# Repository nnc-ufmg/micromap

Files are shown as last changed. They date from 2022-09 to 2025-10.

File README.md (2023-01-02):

MicroMAP: Low cost, high performance package for electrophysiological recording
===============================================================================
<div align="center">
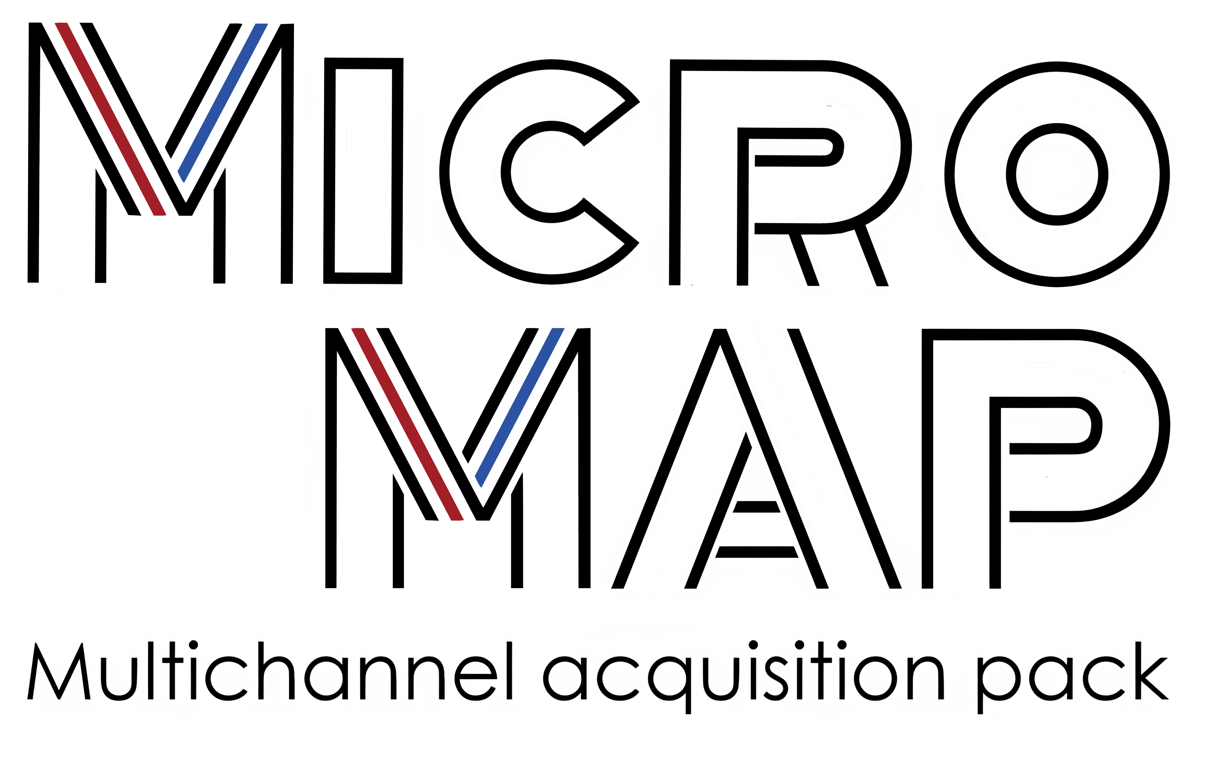
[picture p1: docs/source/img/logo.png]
MicroMAP software
    

<br/>
<br/>

 **About**

**MicroMAP** is a Python based electrophysiological aquisition system that combines the
portability of the raspberry pi and the versatility of the intan chip to harness the powerful 
combination of open source hardware and software to create a low cost, high performance package
for electrophysiological recording.

 **Getting started**

To get started, please see the installation page in the documentation. There you will find instructions on how to install MicroMAP on your raspberry pi and how to get started with the software.

 **Documentation**

_Online link coming soon_

<br/>

_**Note**_
 _This project is currently in its working beta phase._

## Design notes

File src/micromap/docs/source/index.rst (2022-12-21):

===============================================================================
MicroMAP: Low cost, high performance package for electrophysiological recording
===============================================================================

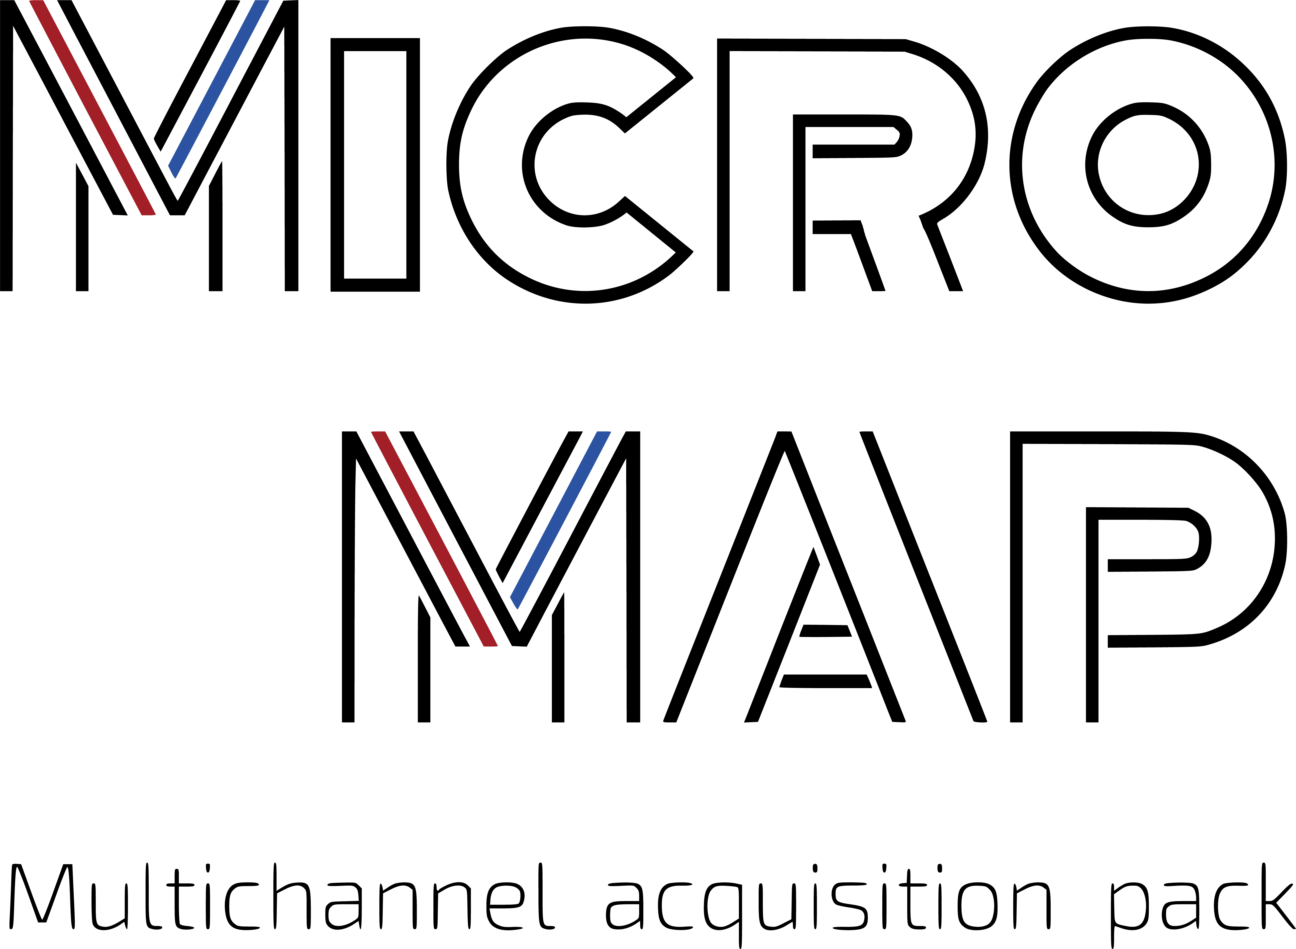
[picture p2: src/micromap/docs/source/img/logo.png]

   
|

.. toctree::
   :hidden:
   :maxdepth: 3

   installation
   modules
   mounting
   tips
   usage

**MicroMAP** is a Python based electrophysiological aquisition system that combines the
portability of the raspberry pi and the versatility of the intan chip to harness the powerful 
combination of open source hardware and software to create a low cost, high performance package
for electrophysiological recording.

To get started, please see the :doc:`/installation` page.
There you will find instructions on how to install MicroMAP on your raspberry pi and how to get started 
with the software.

**Get started**
---------------

* For tips about how to use the software, please see the :doc:`/tips` page
* For a list of all the available options and more detailed information, please see the :doc:`/micromap` page 
* Check out the :doc:`/usage` section for a detailed description of how to use the software

.. note::

  This project is currently in its working beta phase.

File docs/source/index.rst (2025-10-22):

MicroMAP
========

   
|

####################
Welcome to MicroMAP
####################

MicroMAP is a low-cost, multi-channel electrophysiology acquisition system. This documentation provides instructions for installing the necessary software, setting up the hardware, and building the components.

All codes, 3D models, and PCB designs are available at the project's GitHub repository: https://github.com/nnc-ufmg/micromap.

.. toctree::
   :maxdepth: 2
   :caption: Contents:

   installation_python
   installation_arduino
   building_micromap
   building_headstage
   modules/interface_functions
   modules/user_interface

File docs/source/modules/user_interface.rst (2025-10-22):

Interface Visual module
==========================

This module contains functions that are used to display the data acquired by the RHD2000 chip.

These functions are dealing with the interface as a whole. TIn other words, they contain the front-end in which the user will be able 
to choose the acquisition parameters such as sampling frequency, filters and number of channels active during the acquisition.

.. automodule:: micromap.interface.user_interface
   :members:
   :show-inheritance:

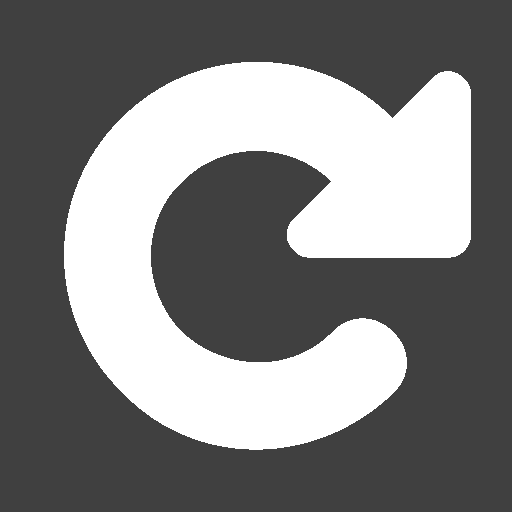
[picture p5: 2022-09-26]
src/micromap/interface/icon/nnc_update_button.png

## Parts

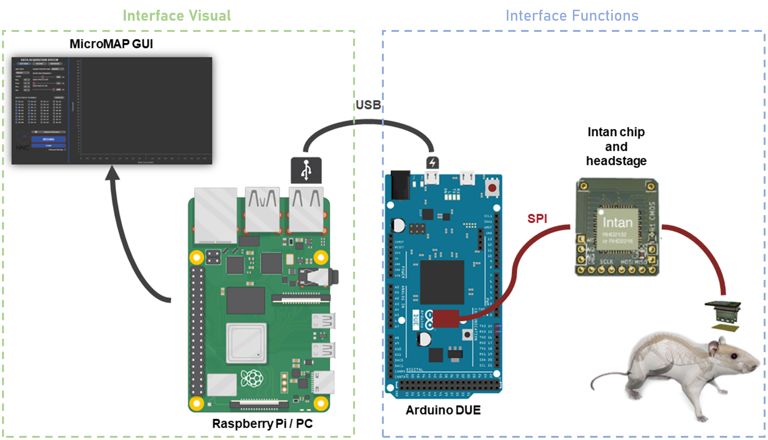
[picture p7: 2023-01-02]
docs/source/img/parts.png

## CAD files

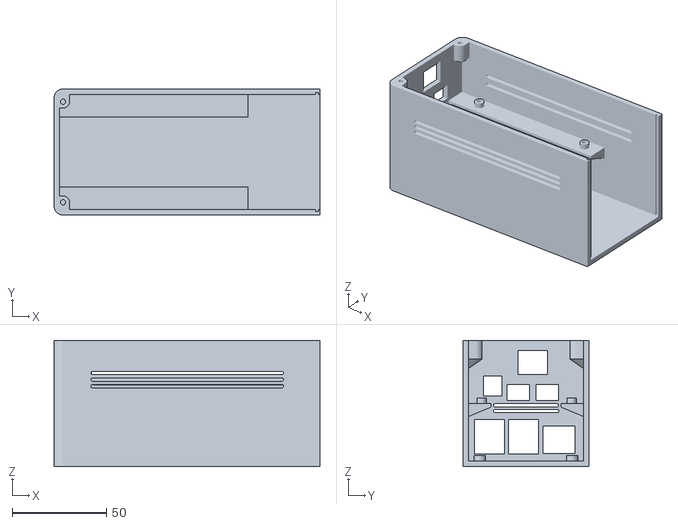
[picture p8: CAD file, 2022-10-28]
src/micromap/case_model/system_case_V2_base.stl
141.2 x 67.0 x 67.1

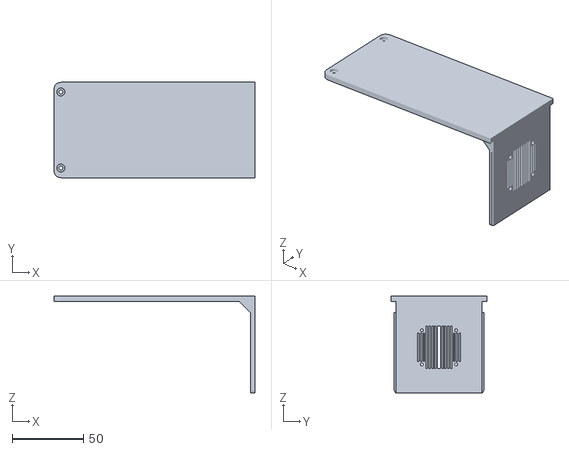
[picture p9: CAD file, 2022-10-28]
src/micromap/case_model/system_case_V2_cover.stl
141.0 x 67.0 x 67.9

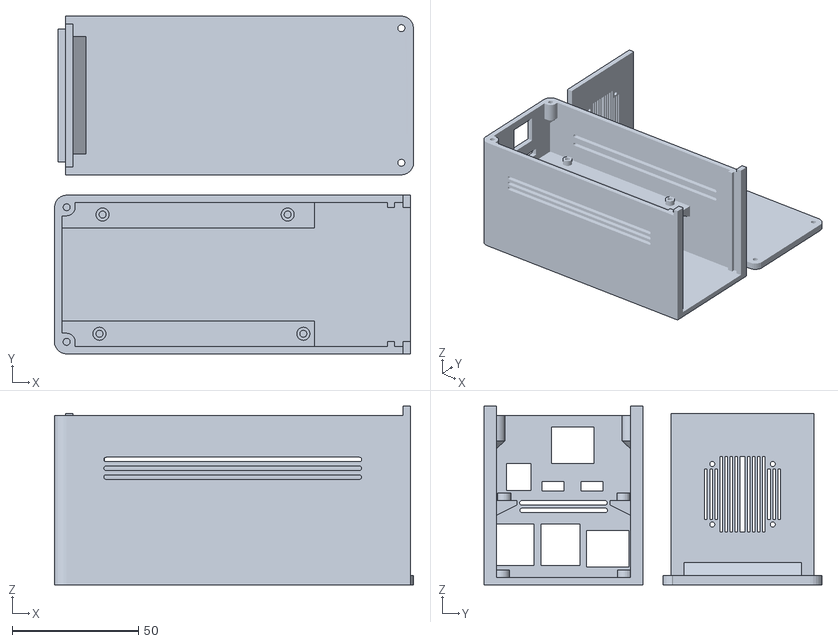
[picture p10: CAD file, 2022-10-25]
src/micromap/case_model/system_case_v2.stl
142.4 x 134.0 x 70.9

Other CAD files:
src/micromap/case_model/arduino_due.skp
src/micromap/case_model/raspberrypi_4.skp

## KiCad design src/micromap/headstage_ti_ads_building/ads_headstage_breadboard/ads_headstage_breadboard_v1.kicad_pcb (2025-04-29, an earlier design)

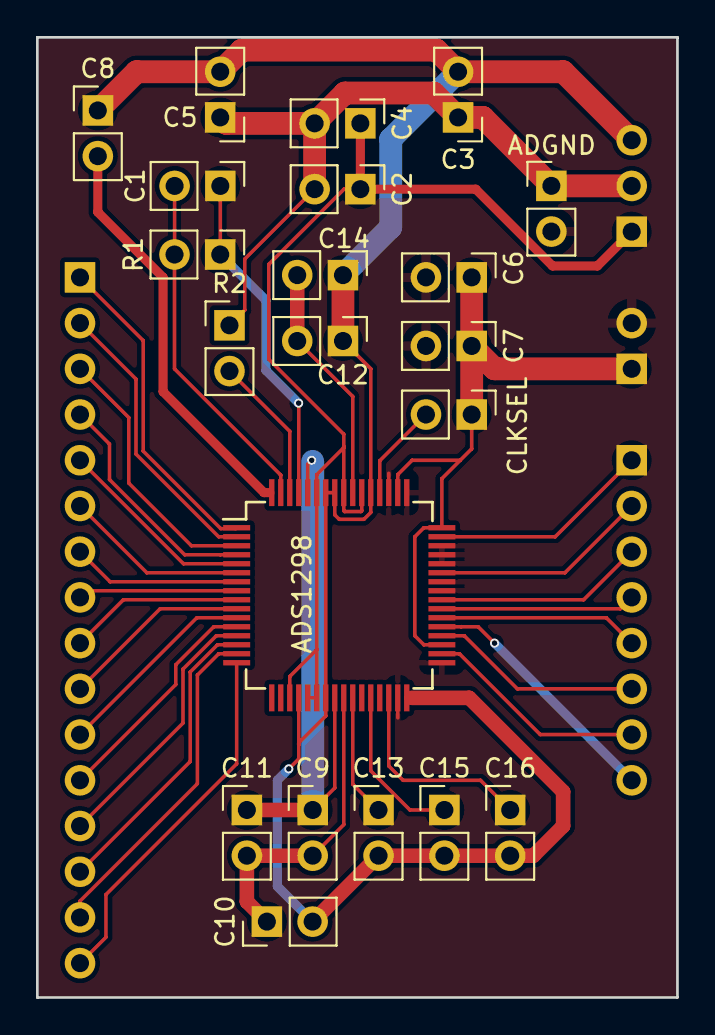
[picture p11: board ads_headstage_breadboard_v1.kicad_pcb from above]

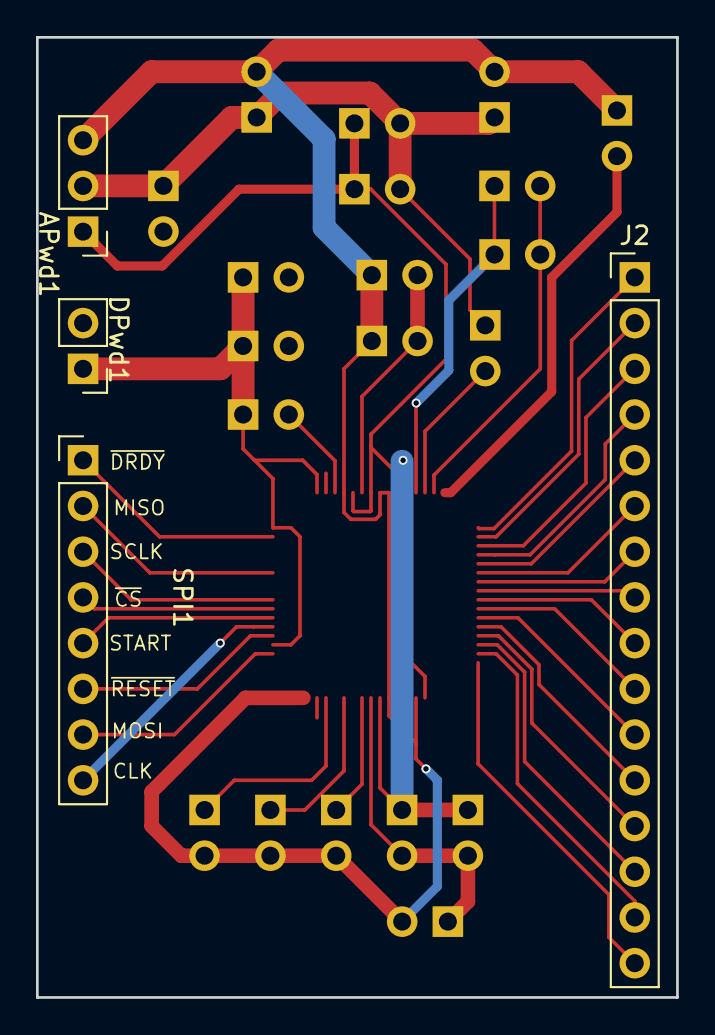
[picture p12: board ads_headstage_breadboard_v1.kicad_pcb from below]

Board: 2 copper layers, 35.6 x 53.3 mm, 25 parts (4 on the bottom side), 40 nets.

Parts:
ADGND: Jumper_NO_Small; PinHeader_1x02_P2.54mm_Vertical
ADS1298: ADS1298; TQFP-64_10x10mm_Pitch0.5mm
APwd1: Conn_01x03; PinHeader_1x03_P2.54mm_Vertical
C1: 1nf; PinHeader_1x02_P2.54mm_Vertical
C2, C3, C6, C10, C12, C13, C16: 1uF; PinHeader_1x02_P2.54mm_Vertical
C4, C5, C7, C9, C14: 0.1uF; PinHeader_1x02_P2.54mm_Vertical
C8: 100pf; PinHeader_1x02_P2.54mm_Vertical
C11: 10uF; PinHeader_1x02_P2.54mm_Vertical
C15: 22uF; PinHeader_1x02_P2.54mm_Vertical
CLKSEL: Jumper_NO_Small; PinHeader_1x02_P2.54mm_Vertical
DPwd1: Conn_01x02; PinHeader_1x02_P2.54mm_Vertical
J2: Conn_01x16_Female; PinHeader_1x16_P2.54mm_Vertical
R1, R2: 1M; PinHeader_1x02_P2.54mm_Vertical
SPI1: Conn_01x08; PinHeader_1x08_P2.54mm_Vertical

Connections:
/ADS1298/RLDIN: ADS1298.62, R2.2
/ADS1298/RLDINV: ADS1298.61, C1.1, R1.1
/ADS1298/RLDREF: ADS1298.24, ADS1298.60, C9.1, C11.1
/AGND: ADGND.1, APwd1.2, C2.2, C3.1, C4.2, C5.1, R2.1
/AVDD: ADS1298.19, ADS1298.21, ADS1298.22, ADS1298.54, ADS1298.56, ADS1298.59, APwd1.1, C2.1, C4.1
/AVSS: ADS1298.20, ADS1298.23, ADS1298.32, ADS1298.53, ADS1298.57, ADS1298.58, APwd1.3, C3.2, C5.2, C8.1, C10.2, C12.1, C13.2, C14.1, C15.2, C16.2
/CLK: ADS1298.37, SPI1.8
/CLKSEL: ADS1298.52, CLKSEL.2
/DGND: ADGND.2, ADS1298.31, ADS1298.33, ADS1298.41, ADS1298.42, ADS1298.44, ADS1298.45, ADS1298.46, ADS1298.49, ADS1298.51, C6.2, C7.2, DPwd1.2
/DVDD: ADS1298.35, ADS1298.48, ADS1298.50, C6.1, C7.1, CLKSEL.1, DPwd1.1
/IN1N: ADS1298.15, J2.15
/IN1P: ADS1298.16, J2.16
/IN2N: ADS1298.13, J2.13
/IN2P: ADS1298.14, J2.14
/IN3N: ADS1298.11, J2.11
/IN3P: ADS1298.12, J2.12
/IN4N: ADS1298.9, J2.9
/IN4P: ADS1298.10, J2.10
/IN5N: ADS1298.7, J2.7
/IN5P: ADS1298.8, J2.8
/IN6N: ADS1298.5, J2.5
/IN6P: ADS1298.6, J2.6
/IN7N: ADS1298.3, J2.3
/IN7P: ADS1298.4, J2.4
/IN8N: ADS1298.1, J2.1
/IN8P: ADS1298.2, J2.2
/MISO: ADS1298.43, SPI1.2
/MOSI: ADS1298.34, SPI1.7
/RDLout: ADS1298.63, C1.2, R1.2
/SPI_CLK: ADS1298.40, SPI1.3
/START: ADS1298.38, SPI1.5
/~CS: ADS1298.39, SPI1.4
/~DRDY: ADS1298.47, SPI1.1
/~RESET: ADS1298.36, SPI1.6
unnamed: ADS1298.25, C9.2, C10.1, C11.2
unnamed: ADS1298.26, C13.1
unnamed: ADS1298.28, C15.1
unnamed: ADS1298.30, C16.1
unnamed: ADS1298.55, C12.2, C14.2
unnamed: ADS1298.64, C8.2

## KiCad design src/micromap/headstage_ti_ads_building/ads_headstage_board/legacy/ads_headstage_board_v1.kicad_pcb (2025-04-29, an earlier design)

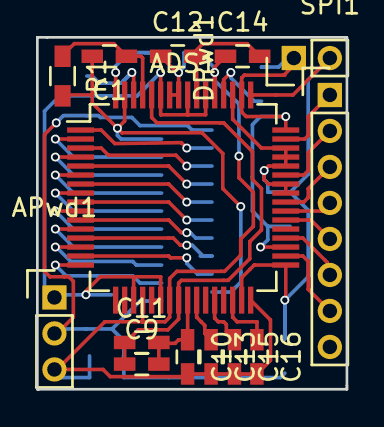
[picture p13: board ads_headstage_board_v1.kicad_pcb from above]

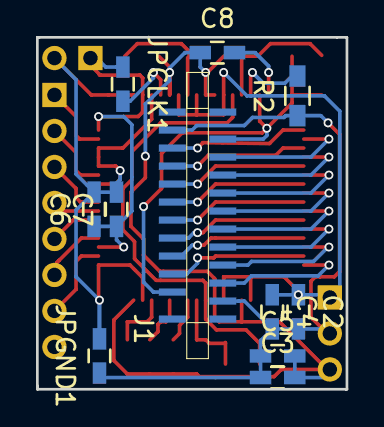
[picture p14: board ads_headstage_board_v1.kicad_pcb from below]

Board: 2 copper layers, 17.2 x 19.5 mm, 25 parts (11 on the bottom side), 39 nets.

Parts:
ADS1: ADS1298; TQFP-64_10x10mm_Pitch0.5mm
APwd1: Conn_01x03; Pin_Header_Straight_1x03_Pitch2.00mm
C1: 1nf; C_0603_HandSoldering
C2, C3, C6, C10, C12, C13, C16: 1uF; C_0603_HandSoldering
C4, C5, C7, C9, C14: 0.1uF; C_0603_HandSoldering
C8: 100pf; C_0603_HandSoldering
C11: 10uF; C_0603_HandSoldering
C15: 22uF; C_0603_HandSoldering
DPwd1: Conn_01x02; Pin_Header_Straight_1x02_Pitch2.00mm
J1: FFCfemale20
JPCLK1: Jumper_NO_Small; C_0603_HandSoldering
JPGND1: Jumper_NO_Small; C_0603_HandSoldering
R1, R2: 1M; R_0603_HandSoldering
SPI1: Conn_01x08; Pin_Header_Straight_1x08_Pitch2.00mm

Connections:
/ADS1298/RLDIN: ADS1.62, R2.2
/ADS1298/RLDINV: ADS1.61, C1.1, R1.1
/ADS1298/RLDREF: ADS1.24, ADS1.60, C9.1, C11.1
/AGND: APwd1.2, C2.2, C3.1, C4.2, C5.1, J1.1, J1.20, JPGND1.1, R2.1
/AVDD: ADS1.19, ADS1.21, ADS1.22, ADS1.54, ADS1.56, ADS1.59, APwd1.1, C2.1, C4.1
/AVSS: ADS1.20, ADS1.23, ADS1.32, ADS1.53, ADS1.57, ADS1.58, APwd1.3, C3.2, C5.2, C8.1, C10.2, C12.1, C13.2, C14.1, C15.2, C16.2
/CLKSEL: ADS1.52, JPCLK1.2
/DGND: ADS1.31, ADS1.33, ADS1.41, ADS1.42, ADS1.44, ADS1.45, ADS1.46, ADS1.49, ADS1.51, C6.2, C7.2, DPwd1.2, JPGND1.2
/DVDD: ADS1.35, ADS1.48, ADS1.50, C6.1, C7.1, DPwd1.1, JPCLK1.1
/IN1N: ADS1.15, J1.17
/IN1P: ADS1.16, J1.18
/IN2N: ADS1.13, J1.15
/IN2P: ADS1.14, J1.16
/IN3N: ADS1.11, J1.13
/IN3P: ADS1.12, J1.14
/IN4N: ADS1.9, J1.11
/IN4P: ADS1.10, J1.12
/IN5N: ADS1.7, J1.9
/IN5P: ADS1.8, J1.10
/IN6N: ADS1.5, J1.7
/IN6P: ADS1.6, J1.8
/IN7N: ADS1.3, J1.5
/IN7P: ADS1.4, J1.6
/IN8N: ADS1.1, J1.3
/IN8P: ADS1.2, J1.4
/MISO: ADS1.43, SPI1.2
/MOSI: ADS1.34, SPI1.7
/RDLout: ADS1.63, C1.2, J1.2, J1.19, R1.2
/SPI_CLK: ADS1.40, SPI1.3
/START: ADS1.38, SPI1.5
/~CS: ADS1.39, SPI1.4
/~DRDY: ADS1.47, SPI1.1
/~RESET: ADS1.36, SPI1.6
unnamed: ADS1.25, C9.2, C10.1, C11.2
unnamed: ADS1.26, C13.1
unnamed: ADS1.28, C15.1
unnamed: ADS1.30, C16.1
unnamed: ADS1.55, C12.2, C14.2
unnamed: ADS1.64, C8.2

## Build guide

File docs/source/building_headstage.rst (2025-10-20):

###########################
4. Building the Headstage
###########################

MicroMAP uses a custom horizontal headstage designed to be low-cost and reduce torque on the animal's head. The system is compatible with two main headstage designs:

* **Texas Instruments (TI) ADS1298**
* **Intan RHD2000 family**

1. Fabrication
==============

* **Get PCB Designs**: The printed circuit board (PCB) designs, created in **KICAD 8**, are available on the project's GitHub.
* **Fabricate PCBs**: Fabricate the main headstage PCB based on the KiCAD files.
* **Fabricate Connector Plug**: A flat connector plug, implemented as a double-sided PCB, is also required. This design uses plated through-holes for soldering the electrodes.

2. Assembly
===========

* **Attach ADC**: The ADC (e.g., ADS1298 or RHD) is attached to the **top layer** of the headstage PCB.
* **Attach Socket**: A 20-pin connector socket is attached to the **bottom layer** of the PCB. This socket interfaces with the flat connector plug.

Refer to Figure 2A (ADS) and 2B (RHD) for 3D renderings and circuit schematics of the headstages.

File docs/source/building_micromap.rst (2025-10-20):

###########################
3. Building the MicroMAP
###########################

This section describes the assembly of the MicroMAP enclosure, which houses the core components.

1. 3D Printing the Enclosure
============================

The system is housed in a custom enclosure ($140~mm \times 65~mm \times 67~mm$).

* **Get 3D Models**: All 3D models are available on the project's GitHub.
* **Print**: Fabricate the enclosure from PLA plastic using a 3D printer.

2. Component Assembly
=====================
The enclosure is designed to house the **Arduino Due** and a **Raspberry Pi** (RPi).

* Install the Arduino Due and RPi into their designated slots in the 3D-printed case.
* (Optional) A fan can be added for cooling, powered by the RPi's 5V and ground pins.

3. Wiring
=========

The system requires wiring between the Arduino and an external connector (e.g., RJ45) to interface with the headstage.

* **RHD Headstage**: Requires an 8-contact RJ45 connector, using 6 terminals.
* **ADS Headstage**: Requires a 12-contact connector or similar interface.

Refer to Figure 1A and Supplementary Table 2 in the manuscript for detailed wiring schemes between the Arduino and the headstage connector.

Finally, connect the Arduino ground to a pin fixed to the enclosure to ensure proper grounding.

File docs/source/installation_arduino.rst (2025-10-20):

###################################
2. Installing the Arduino Interface
###################################

The MicroMAP system uses an **Arduino Due** as the microcontroller to handle communication and control of the ADC chipsets (Intan RHD or TI ADS).

Hardware & Software Requirements
================================

* **Hardware**: Arduino Due
* **Software**: Arduino IDE

Uploading the Code
==================

The microcontroller code is programmed in C++ and must be uploaded to the Arduino Due.

1.  **Download the Code**

    The microcontroller code is available in the same GitHub repository.

2.  **Open in Arduino IDE**

    Launch the Arduino IDE and open the `.ino` file for the microcontroller found in the downloaded repository.

3.  **Configure the IDE**

    * Connect your Arduino Due to the computer via USB.
    * In the Arduino IDE, go to ``Tools > Board`` and select "Arduino Due (Programming Port)".
    * Go to ``Tools > Port`` and select the COM or tty port corresponding to your Arduino Due.

4.  **Upload**

    Click the "Upload" button (right-arrow icon) in the Arduino IDE to compile and upload the code to the Arduino Due.

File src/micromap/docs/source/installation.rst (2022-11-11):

Installation
============

To get the program up and running of your Raspberry Pi
you will need to:

1. Install Raspberry Pi OS 
2. Configure the VNC package in the Raspberry Pi
3. Install the the dependecies on the Raspberry Pi

Raspberry Pi OS installation
------------------------------

- Install the Raspberry Pi OS on your Raspberry Pi

Raspberry Pi VNC Configuration
------------------------------

- Open the *Raspbperry Pi Configurations* in *Applications Menu*
- Go to *Interfaces* tab and turns on the VNC
- Go to *Display* tab and sets the *Headlesss Resolution* to maximum value (1920x1080)
- On the task bar right side a VNC symbol will appear
- Click on it and gets the IP on left side of the window (ex. 192.168.1.222)
- Install and open the *VNC Viewer* on another computer (https://www.realvnc.com/pt/connect/download/viewer/)
- Open the *VNC Viewer*, click in *file* tab and after, in *new connection* 
- Put the Raspberry Pi VNC IP on *VNC Server* item and complete with the login
- Turns on the Raspberry Pi and connect with VNC Viewer to acess remotely

Installing dependecies
----------------------

- Open a terminal inside the Raspberry Pi
- Install the libraries with the command:

.. code-block:: bash

  $ pip install -r requirements.txt

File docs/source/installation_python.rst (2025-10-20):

#################################
1. Installing Python and MicroMAP
#################################

The MicroMAP system uses a cross-platform Graphical User Interface (GUI) developed in Python 3.12 with the PyQt5 library. This GUI runs on a host computer or a microcomputer like a Raspberry Pi.

Prerequisites
=============

* Python 3.12 or newer
* Git (for cloning the repository)

Installation Steps
==================

1.  **Download the Software**

    First, download the software from the official GitHub repository.

    .. code-block:: bash

        $ git clone https://github.com/nnc-ufmg/micromap.git
        $ cd micromap

2.  **Install Dependencies**

    The GUI requires specific Python dependencies to run. Install them using the provided requirements file (assumed to be on GitHub). The primary dependency is PyQt5.

    .. code-block:: bash

        $ pip install -r requirements.txt 

3.  **Run the GUI**

    Once dependencies are installed, you can run the program from an IDE or directly via the command line.

    .. code-block:: bash

        $ python interface_visual.py

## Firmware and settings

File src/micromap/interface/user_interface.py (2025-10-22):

# ELECTROPHYSIOLOGICAL DATA ACQUISITION SYSTEM

# This code is the configuration part of the electrophysiology recording 
# system. This partition contains the front-end, in which the user will be able 
# to choose acquisition parameters such as sampling frequency, filters and number 
# of channels.

# Author: 
#     João Pedro Carvalho Moreira
#     Belo Horizonte, Minas Gerais, Brasil
#     Graduated in Eletrical Engineer, UFSJ
#     PhD Student in Eletrical Engineer, UFMG
#     Member of Núcleo de Neurociências, UFMG

# Advisor: 
#     Márcio Flávio Dutra Moraes

#%% IMPORTS

import sys
import numpy 
import serial
import math
import serial.tools.list_ports
import time
import struct
import queue
from . import interface_functions as interface_functions      
import os
import platform
import pickle
from datetime import datetime, timedelta
from PyQt5 import QtWidgets, uic    
from PyQt5.QtCore import QThread, pyqtSignal, QCoreApplication, QTimer
from PyQt5.QtWidgets import QMessageBox, QMainWindow, QInputDialog, QFileDialog
import platform
from pyqtgraph.Qt import QtGui
import pyqtgraph

class DataReceiverThreadRHD(QThread):
    raw_data_ready = pyqtSignal(bytearray)
    message = pyqtSignal(str)

    def __init__(self, usb_port, num_channels, samples_to_read, is_recording_mode, plot_online, save_queue = None):
        super().__init__()
        self.usb = interface_functions.usb_singleton(usb_port, 50000000)
        self.num_channels = num_channels
        self.samples_to_read = samples_to_read
        self.bytes_to_read = int(samples_to_read*(2*(self.num_channels + 1)))                                                                         # Number of bytes to be read at a time (in this case, at a time will be read 1 sample = 2 bytes per channel + 1 byte header)
        self.running = False
        self.is_recording_mode = is_recording_mode
        self.save_queue = save_queue
        self.expected_counter = None
        self.buffer = bytearray()
        self.read_number = 0
        self.plot_online = plot_online
        self.packets_lost = []

    def run(self):
        self.running = True
        self.usb.connect()
        self.usb.clear_buffer()
        self.usb.request_acquisition()

        while self.running:
            if self.usb.port.in_waiting > 0:
                try:
                    partial_data = self.usb.port.read(self.usb.port.in_waiting)
                    self.buffer += partial_data

                    if self.plot_online:
                        self.raw_data_ready.emit(bytearray(partial_data))

                    while len(self.buffer) >= self.bytes_to_read:                      
                        full_packet = self.buffer[:self.bytes_to_read]
                        self.buffer = self.buffer[self.bytes_to_read:]

                        if self.expected_counter is None:
                            self.expected_counter = int.from_bytes( full_packet[0:2], byteorder='big')  # Convert to integer

                        packet_counter = int.from_bytes(full_packet[0:2], byteorder='big')  # Convert to integer
                        
                        if packet_counter != self.expected_counter:
                            self.message.emit(f"[ERROR] Packet counter mismatch: expected {self.expected_counter}, got {packet_counter}")
                            self.packets_lost.append(numpy.abs(packet_counter - self.expected_counter))  # Store the difference in packet counters
                            self.expected_counter = packet_counter                                       # Update the expected counter to the received one

                        self.expected_counter = (self.expected_counter + self.samples_to_read) % 65536  # Increment the expected counter

                        if self.is_recording_mode and self.save_queue:
                            self.save_queue.put(full_packet)  

                        self.message.emit(f'[RECEIVE] {self.read_number}')
                        self.read_number += 1

                except Exception as e:
                    self.message.emit(f"[ERROR]: {e}")

        if len(self.buffer) > 0:
            if self.is_recording_mode and self.save_queue:
                self.save_queue.put(self.buffer)
                self.message.emit(f'[RECEIVE] {self.read_number}')
                self.read_number += 1

        if self.packets_lost != []:
            self.message.emit(f"[INFO] Stopping data acquisition... ({numpy.sum(self.packets_lost)} packets lost)")
        else:
            self.message.emit(f"[INFO] Stopping data acquisition... (No packets lost)")
        self.usb.stop_acquisition()
        self.usb.disconnect()

    def stop(self):
        self.running = False

    def online_plotting(self, state):
        self.plot_online = state

class DataReceiverThreadADS(QThread):
    raw_data_ready = pyqtSignal(bytearray)
    message = pyqtSignal(str)

    def __init__(self, usb_port, num_channels, samples_to_read, is_recording_mode, plot_online, save_queue = None):
        super().__init__()
        self.usb = interface_functions.usb_singleton(usb_port, 50000000)
        self.num_channels = num_channels
        self.samples_to_read = samples_to_read
        self.bytes_to_read = int(samples_to_read*(216//8))                                                                                            # Number of bytes to be read at a time (in this case, at a time will be read 1 sample = 2 bytes per channel + 1 byte header)
        self.running = False
        self.is_recording_mode = is_recording_mode
        self.save_queue = save_queue
        self.expected_counter = None
        self.buffer = bytearray()
        self.read_number = 0
        self.plot_online = plot_online
        self.packets_lost = []

    def run(self):
        self.running = True
        self.usb.connect()
        self.usb.clear_buffer()
        self.usb.request_acquisition()

        while self.running:
            if self.usb.port.in_waiting > 0:
                try:
                    partial_data = self.usb.port.read(self.usb.port.in_waiting)
                    self.buffer += partial_data

                    if self.plot_online:
                        self.raw_data_ready.emit(bytearray(partial_data))

                    while len(self.buffer) >= self.bytes_to_read:                      
                        full_packet = self.buffer[:self.bytes_to_read]
                        self.buffer = self.buffer[self.bytes_to_read:]

                        if self.is_recording_mode and self.save_queue:
                            self.save_queue.put(full_packet)  

                        self.message.emit(f'[RECEIVE] {self.read_number}')
                        self.read_number += 1

                except Exception as e:
                    self.message.emit(f"[ERROR]: {e}")

        if len(self.buffer) > 0:
            if self.is_recording_mode and self.save_queue:
                self.save_queue.put(self.buffer)
                self.message.emit(f'[RECEIVE] {self.read_number}')
                self.read_number += 1

        if self.packets_lost != []:
            self.message.emit(f"[INFO] Stopping data acquisition... ({numpy.sum(self.packets_lost)} packets lost)")
        else:
            self.message.emit(f"[INFO] Stopping data acquisition... (No packets lost)")
        self.usb.stop_acquisition()
        self.usb.disconnect()

    def stop(self):
        self.running = False

    def online_plotting(self, state):
        self.plot_online = state

class PlotThreadRHD(QThread):
    channel_data_ready = pyqtSignal(numpy.ndarray)
    message = pyqtSignal(str)

    def __init__(self, num_channels, plot_data_window, update_samples = 1000, parent=None):
        super().__init__(parent)    
        if plot_data_window < update_samples:
            raise ValueError("plot_data_window must be greater than update_samples")
        
        self.queue = queue.Queue()
        self.num_channels = num_channels
        self.update_bytes = update_samples*(2*(self.num_channels + 1))
        self.intan_scale = 1000 * 0.195e-6
        self.running = True
        self.update_buffer = numpy.zeros((self.num_channels, plot_data_window), dtype = numpy.float32)
        self.update_index = 0
        self.buffer_size = self.update_buffer.shape[1]

        print(f"[INFO] Buffer size: {self.buffer_size}")

        self.block_size = 2*(self.num_channels + 1)  # 2 bytes por amostra + 2 bytes cabeçalho
        self.flag_indexes_template = numpy.ones(self.block_size, dtype = bool)
        self.flag_indexes_template[0:2] = False

    def push_data(self, byte_data):
        self.queue.put(byte_data)

    def run(self):
        accumulated_bytes = 0
        byte_block = bytearray()

        while self.running:
            try:
                byte_data = self.queue.get(timeout=0.1)
                byte_block.extend(byte_data)
                accumulated_bytes += len(byte_data)

                if accumulated_bytes >= self.update_bytes:
                    repeats = len(byte_block) // self.block_size
                    flag_indexes = numpy.tile(self.flag_indexes_template, repeats)
                    
                    # Processa o pacote
                    clean_bytes = numpy.frombuffer(byte_block, dtype = numpy.uint8)[flag_indexes].tobytes()
                    unpack_format = "<" + str(len(clean_bytes)//2) + "h"
                    values = struct.unpack(unpack_format, clean_bytes)
                    channel_data = numpy.array([values[i::self.num_channels] for i in range(self.num_channels)], dtype=numpy.float32)
                    channel_data = channel_data * self.intan_scale

                    # Atualiza buffer
                    update_length = channel_data.shape[1]
                    end_index = (self.update_index + update_length) % self.buffer_size

                    if self.update_index < end_index:
                        self.update_buffer[:, self.update_index:end_index] = channel_data
                    else:
                        first_part = self.buffer_size - self.update_index
                        self.update_buffer[:, self.update_index:] = channel_data[:, :first_part]
                        self.update_buffer[:, :update_length - first_part] = channel_data[:, first_part:]

                    self.update_index = end_index

                    self.channel_data_ready.emit(self.update_buffer.copy())

                    # Reseta acumuladores
                    accumulated_bytes = 0
                    byte_block = bytearray()

            except queue.Empty:
                continue
    
    def stop(self):
        self.running = False

class PlotThreadADS(QThread):
    channel_data_ready = pyqtSignal(numpy.ndarray)
    message = pyqtSignal(str)

    def __init__(self, num_channels, plot_data_window, update_samples=1000, parent=None):
        super().__init__(parent)
        if plot_data_window < update_samples:
            raise ValueError("plot_data_window must be greater than update_samples")

        self.queue = queue.Queue()
        self.num_channels = num_channels
        self.update_bytes = update_samples * (3 * (self.num_channels + 1))  # 3 bytes por canal + 3 de header
        self.ads_scale = 0.488e-6 * 1000  # microvolts para milivolts
        self.running = True
        self.update_buffer = numpy.zeros((self.num_channels, plot_data_window), dtype=numpy.float32)
        self.update_index = 0
        self.buffer_size = self.update_buffer.shape[1]

        print(f"[INFO] Buffer size: {self.buffer_size}")

        self.block_size = 3 * (self.num_channels + 1)  # 3 bytes de header + 3 bytes por canal
        self.flag_indexes_template = numpy.ones(self.block_size, dtype=bool)
        self.flag_indexes_template[0:3] = False  # Ignora os 3 bytes do status word

    def push_data(self, byte_data):
        self.queue.put(byte_data)

    def run(self):
        accumulated_bytes = 0
        byte_block = bytearray()

        while self.running:
            try:
                byte_data = self.queue.get(timeout=0.1)
                byte_block.extend(byte_data)
                accumulated_bytes += len(byte_data)

                if accumulated_bytes >= self.update_bytes:
                    repeats = len(byte_block) // self.block_size
                    flag_indexes = numpy.tile(self.flag_indexes_template, repeats)

                    # Remove status word
                    clean_bytes = numpy.frombuffer(byte_block, dtype=numpy.uint8)[flag_indexes].tobytes()

                    # Reconstrói os valores de 24 bits -> 32 bits assinados
                    values = []
                    for i in range(0, len(clean_bytes), 3):
                        b1, b2, b3 = clean_bytes[i:i+3]
                        val = b1 << 16 | b2 << 8 | b3
                        if val & 0x800000:
                            val -= 0x1000000  # Sign extension para 2's complement
                        values.append(val)

                    values = numpy.array(values, dtype=numpy.float32)
                    values *= self.ads_scale * 0.01

                    channel_data = numpy.array([values[i::self.num_channels] for i in range(self.num_channels)])

                    update_length = channel_data.shape[1]
                    end_index = (self.update_index + update_length) % self.buffer_size

                    if self.update_index < end_index:
                        self.update_buffer[:, self.update_index:end_index] = channel_data
                    else:
                        first_part = self.buffer_size - self.update_index
                        self.update_buffer[:, self.update_index:] = channel_data[:, :first_part]
                        self.update_buffer[:, :update_length - first_part] = channel_data[:, first_part:]

                    self.update_index = end_index
                    self.channel_data_ready.emit(self.update_buffer.copy())

                    # Reseta
                    accumulated_bytes = 0
                    byte_block = bytearray()

            except queue.Empty:
                continue

    def stop(self):
        self.running = False

class SaveThread(QThread):
    message = pyqtSignal(str)
    
    def __init__(self, filename, save_queue):
        super().__init__()
        self.save_queue = save_queue
        self.filename = filename
        self.running = True
        self.save_number = 0

    def run(self):
        with open(self.filename, 'wb') as f:
            while self.running or not self.save_queue.empty():
                try:
                    data = self.save_queue.get(timeout=0.1)
                    f.write(data)
                    f.flush()
                    self.message.emit(f'[SAVE] {self.save_number}')
                    self.save_number += 1
                except queue.Empty:
                    continue

    def stop(self):
        self.running = False

# INTERFACE CLASS
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

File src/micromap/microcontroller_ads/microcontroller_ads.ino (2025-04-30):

/*  INCLUDES
 *  Initializes the librarys that will be used
 */
#include "microcontroller_ads.h"

/*  SETUP THE COMMUNICATION
 *  This function initializes the USB and the SPI ports
 */
void setup() 
{
  SerialUSB.begin(50000000);                                                                      // Starts the high speed USB transfer port (50MB)
  USART0config(8); 
  ads_1298_chip.init_default(4, 13, 25, 53, 2000, 47);
}

/*  COMMUNICATION LOOP
 *  This function initializes the USB and the SPI communication
 */
void loop() 
{
  if(Serial.available())                                                                          // Deal with what comes via USB
  {
      
  }
  
  if(SerialUSB.available())                                                                       // Deal with what comes in via high speed USB
  {
    ads_1298_chip.setting_command();
  }
  
  if(transfer_data_flag)                                                                          // If has data in buffer (flag is True)
  {
    transfer_data_flag = false;                                                                   // Sets the flag to Flase
    SerialUSB.write((byte *)ads_1298_chip.buffer, 3*ads_1298_chip.channel_count + 3);
  }
}

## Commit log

2022-09-26 Version 0.0 files
    All the files that have been produced so far have been attached to the repository. This is the functional version 0.0 that we will start working on as a team
    [arduino_due.skp, raspberrypi_4.skp]
2022-09-26 Version 0.0 - Upload all files
    In this commit all files produced to build the system was uploaded. This is the version 0.0 and is the group work starting point.
    [arduino_due.skp, raspberrypi_4.skp]
2022-10-12 Fixed two buttons on the advanced tab Both CONTINUE TO RECORD and CANCEL were clipping through the command window.
    - Changed the size of the buttons
    - Moved the command response window slightly up
2022-10-12 Fix clipping buttons in the advanced tab
    - CONTINUE TO RECORD and CANCEL buttons
    that are on the bottom half of the tab were clipping
    through the bottom of the screen
2022-10-12 Minor correction to ADC chip label
2022-10-14 Removal of unused buttons:
    - Remove unused zoom_in buttons
2022-10-14 Add reminder to check the timer function
    The timer function is not working properly. It is not showing the right
    cloked time. This is a reminder to check the timer function.
    - a TODO was added to the code in the interface_visual.py file
    - see line 824
2022-10-15 "Type here" text in advanced tab commands now disappears when clicked
    - fix the placeholderText not disappearing when clicked
    - Added gitignore file
    - Temporarily enables the advanced tab for testing
    The placeholder text was inserted in the wrong place inside of the
    QLineEdit object.
    In the old version it was inserted in the text property of the QLineEdit
    object, but it should be inserted in the placeholderText property.
    This is now fixed.
2022-10-21 Add stylesheet to the main window instead of specific widgets to avoid a bug in which the scrollbar was not stylized correctly.
    - Add stylesheet to MainWindow QWidget
    - Add stylesheet to the NNC_inBrain layout
    - Adjust buttons that were not aligned correctly in the advanced tab
2022-10-24 Create system_case_V2.skp
    Case v2.
    Update and Fixes:
    - removed ghost lines
    - improved expansion spaces
    - height increased
    - socket pins removed. Replaced by screws holes.
    - ventilation slots created
    - printed support for the arduino shelf.
    - opening for the 8-pin female RJ11 connector.
    - accesses on the cover closed .
    - design details changed
2022-10-25 System Case_update_02
    - R11 position adjusted
    - *stl and gcode and *x3g filed updated
    [system_case_V2_base.stl, system_case_V2_cover.stl, system_case_v2.stl]
2022-10-26 System case update
    Change:
    - incresed width by 4 mm.
    - *.x3g file from flash forge software
    [system_case_V2_base.stl, system_case_V2_cover.stl, system_case_v2.stl]
2022-10-28 System case update V2
    - Changed back design and screw holes position
    - *.x3g files from flash forge software uploaded
    - *.stl files uploaded
    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
    [system_case_V2_base.stl, system_case_V2_cover.stl]
2022-10-31 Update all files and analysis
    - Added experiment data
    - Updated the analysis code
    - Updated old files
    - Renamed files and folders
    [system_case_V2_base.stl, system_case_V2_cover.stl, system_case_v2.stl]
2022-10-31 Update the data analysis - The OpenEphys data was recorded in 1000Hz (because I don't know) - Rename some files - Update de code to adapt to new folders
2022-11-17 Create pip install
    - Organize the repo to be pip installable
    - Created __init__.py files to include the folders as modules
    [arduino_due.skp, raspberrypi_4.skp, system_case_V2_base.stl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]
2022-11-18 Update documentation
    - Mounting tutorial
2022-11-24 Renamed the mounting.srt file to the correct extension mounting.rst
    - Added new section to index.rst
    - Fixed the figure indexing inside conf.py and index.rst that was
    causing the figures to not be displayed
    - Added a line separator inside the index.rst below the figure using
    the "|" character
    - Removed an "x" character in mounting.rst that were causing a warning
    when creating the html files
2022-12-01 Add ToolTip
    Addition of Tooltips to application buttons and titles
2022-12-03 Edit conf.py to add autodoc feature
    - Add "os" and "sys" imports
    - Add a path insertion (py modules path two
    directories above
    - Add autodoc to extensions list
2022-12-03 Create autodoc files
    - Created modules file to be a module index
    - Currently we only have 1 module (micromap)
    - Created the micromap.rst file to gather all functions and
    classes
    - Currently the subdivision is being done inside of
    micromap.interface.rst
    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
2022-12-24 Changed the conf.py file to add the correct path insertion
    - The folder structure now is changed, so the
    inclusion should reflect that (Being that the main
    package is inside of a src folder)
2024-10-10 Major changes in threads
    - Change the plot threads
    - Threadpool stead threads
    - Is not the final version
2024-10-22 Correcting the plot and testing the new plotter
    [interface_functions.py]
2024-10-24 Plot fixed and progress bar fixed
    - Thread to progress bar
    - Fixed thread to plot
    - This version is FUNCTIONAL
2024-11-04 Last threads update
    - The threads are working and simple
    - Thread to update the statistics
    - Data saving is working
2025-04-17 Update new way to read bytes from arduino
2025-04-20 Publishing updates
    - New threads to read and save
    - New way to save data
    - Plot optimization
    - Read functions and new class to read MicroMAP data
2025-04-21 Plot optimization
    - Thread to plot
    - Plot now is updated by time (second to second)
2025-04-21 Raspberry Pi adjust
2025-04-29 Repo cleaning
    - Deleted old folders and codes
    - Renamed one analysis file
    - Moved one analysis file to correct folder
    [interface_functions.py]
2025-04-29 Plot bug fixes
    - Update the plot thread
    - Rename the interface code
    [user_interface.py]
2025-04-29 Add the PCB files
    - ADS headstage design
    - ADS breadboard design
    - Rename some files
    - Delete old/unused files
    [ads_headstage_board_notrace_v1.kicad_pcb, ads_headstage_board_notrace_v2.kicad_pcb, ads_headstage_board_trace_v2.kicad_pcb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]
2025-04-30 Updates on ads functions and square
    - Clean data
    [file5AD0D78A.kicad_sch]
2025-10-22 Fix some problems when building documentation
    - "ModuleNotFoundError: No module named 'interface_functions'\n"] [autodoc.import_object]
    - Fixed by renaming interface_visual to "user_interface" to reflect the name of the current source file and changing the import statement to from . import interface_functions as interface_functions.
    - Note: By doing this the program cannot be run by using user_interface.py as a single script, as it throws an error (no parent package). This is fixed bu running the interface as python -m micromap.interface.user_interface from the uppermost directory (i.e.: ./src)
    - Fixed inconsistency problems:
    - WARNING: document isn't included in any toctree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
    [user_interface.py]
